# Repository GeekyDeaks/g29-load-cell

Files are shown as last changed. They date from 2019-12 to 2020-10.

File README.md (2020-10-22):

# G29 Load Cell Mod

Modification to replace the stock brake pedal sensor on a Logitech G29 pedal set with a load cell,
the purpose of which is to more closely simulate a real brake system which is dependent on
the force applied to the pedal and not the pedal position

I assume this would work on the G920 without any issues, and possibly the G27 and G25,
however I have not had the opportunity to test.

It uses a cheap load cell with two closely matched 1k resistors arranged in a
[Wheatstone bridge](https://en.wikipedia.org/wiki/Wheatstone_bridge)
and an Instrumentation Op-Amp.  The cell is mounted in a 3D printed
model that replaces the lower half of the brake piston assembly

There is a digital version by [SkiDude88](https://github.com/Skidude88/Skidude88-G29-PS4-LoadCell-Arduino/wiki) 
using an HX711, that often comes bundled with the load cells, and an Arduino

Assembly re-uses the spring and rubber block, along with a short piece of M10 rod.
The adjustment of the location of the washer and the protrusion of the top nut
allow changes to the first stage of the pedal, which is designed to simulate
the initial feel of the pedal as the pads move into contact with the disc.

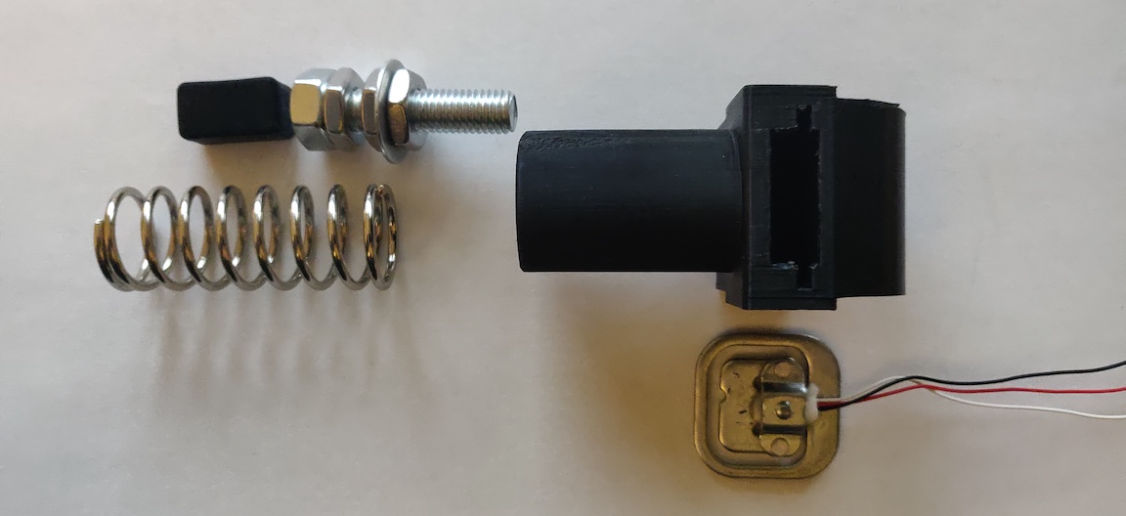
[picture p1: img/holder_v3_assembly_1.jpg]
holder parts

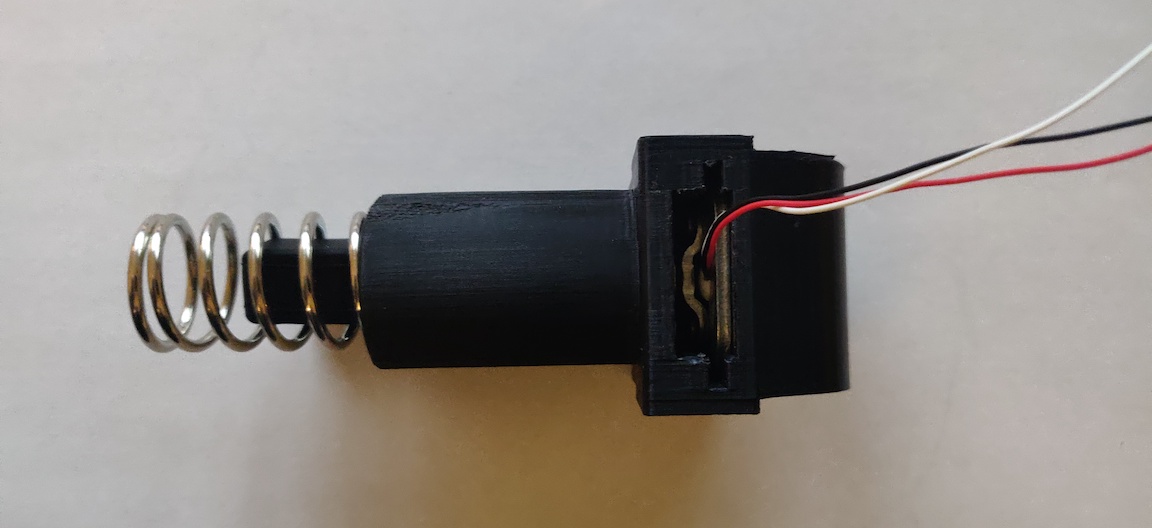
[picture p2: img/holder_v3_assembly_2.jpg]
holder assembled


Fully installed, with the amplifier circuit mounted in a small case

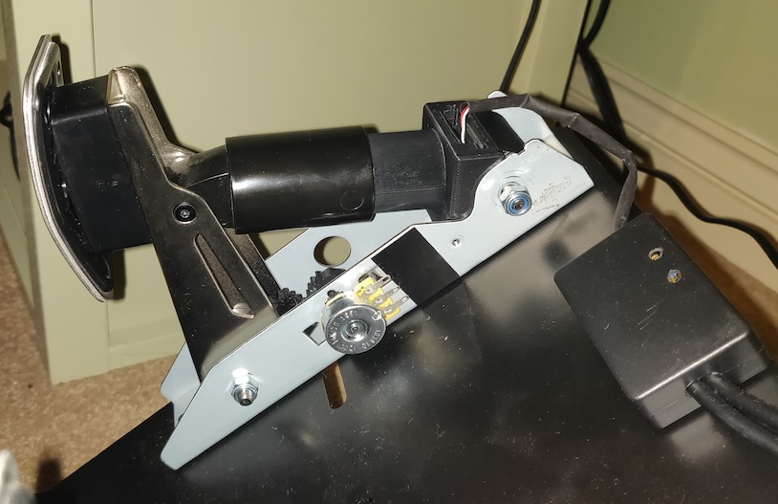
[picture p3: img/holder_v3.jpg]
load cell holder


2020-10-22 UPDATE

Working on a 3D printed plunger to remove the need to cobble one together

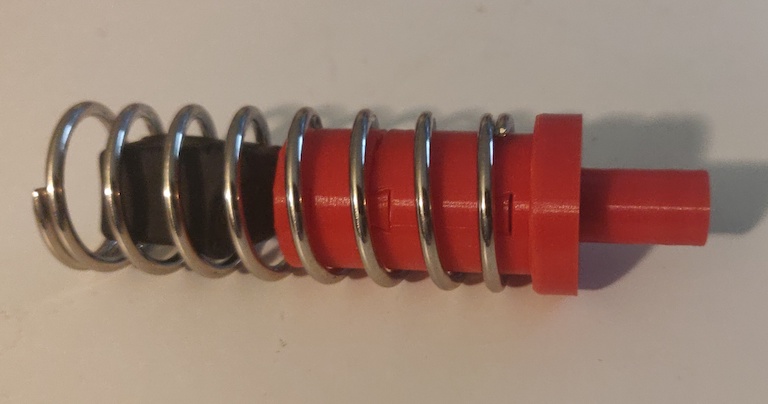
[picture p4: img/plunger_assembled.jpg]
plunger_assembled

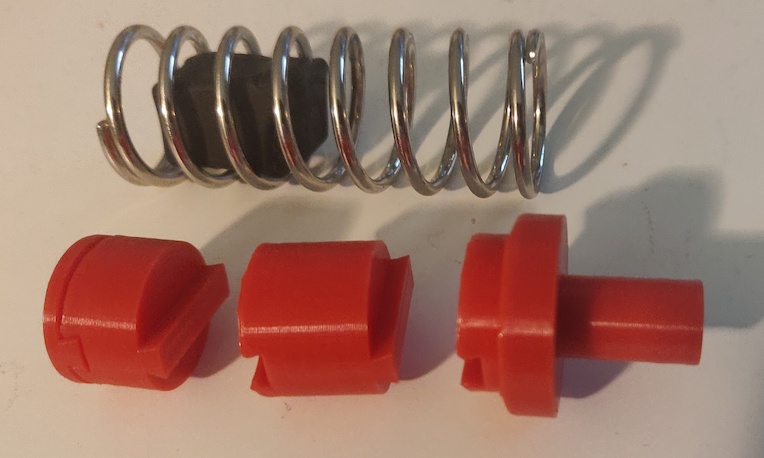
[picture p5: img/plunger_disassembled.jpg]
plunger_disassembled


# Shopping list

1. 3D printer capable of 80mm x 43mm x 43mm
2. Bathroom scale type loadcells
3. PCB copper board or stripboard (35mm x 30mm)
4. INA122P instrumentation amplifier
5. 1k trim pot
6. 10ohm trim pot 
7. 2x 1k resistor
8. 100ohm resistor (fake clutch)
9. 900ohm resistor (fake clutch)
10. M10 thread ~30mm
11. 3x Half height M10 nuts
12. 1x M10 nut
13. M10 to 24mm washer

# Software used

1. EAGLE https://www.autodesk.co.uk/products/eagle/free-download
2. Fusion 360 https://www.autodesk.com/campaigns/fusion-360-for-hobbyists

# Load Cells

The load cells are cheap bathroom scale variety.  I got mine from Amazon:

https://www.amazon.co.uk/gp/product/B07TWLP3X8

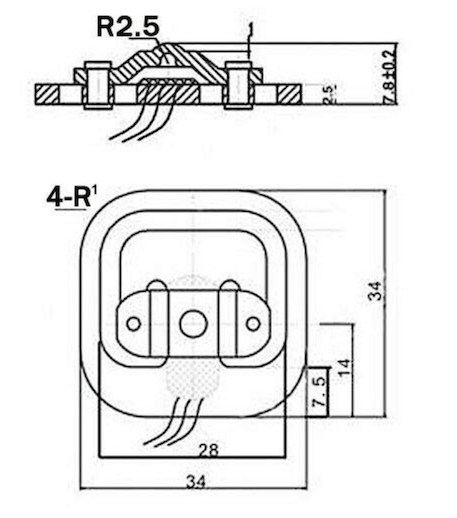
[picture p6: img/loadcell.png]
load cell dimensions


Each cell is comprised of two resistors one which increases under load (white) and the 
other which decreases (black).  Zero load is approx 1k, with about 2-3 Ohm change under heavy load

# Amplifier Circuit

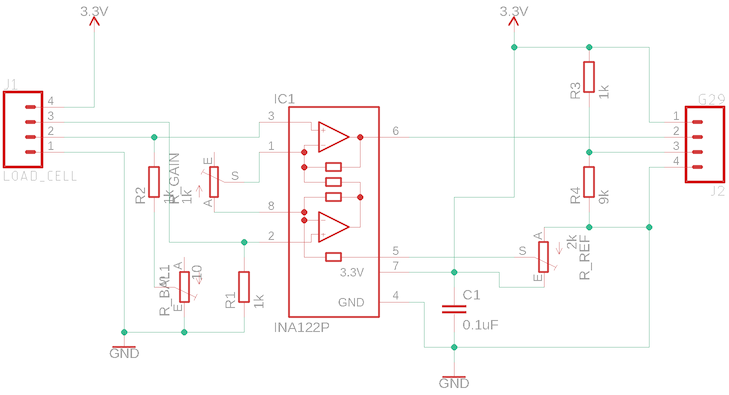
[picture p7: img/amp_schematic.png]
amp schematic


The loadcell is connected to the circuit as follows:

1. Red -> 3.3v
2. Black -> V+
3. White -> V-

Since we need to output a higher voltage with no load on the cells 
we have to unbalance the bridge so that load brings it back into balance.

The 1k resistors for `R1` and `R2` should be measured and the larger of the two should
be used for `R1` to allow `R_BAL1` to adjust the link with `R2` and force the bridge out of 
balance with no load

`R_REF` should be replaced with a link from the middle pin to the right pin.  This
will tie the `REF` pin on the INA122P to ground.
It was originally used when the design had two load cells
and the INA122P was inverting the gain.

Astute observers may have noticed the connections for the loadcell appear to be
reversed in reference to V+ and V-.  This is because the labelling on the PCB of 
V+ and V- was in reference to the dual load cell configuration and hence the 
labels on the PCB are not correct for a single cell.

## Clutch

The circuit also allows for simulating a clutch, allowing it to be removed if desired.
The G29 has been known to glitch if the clutch is disconnected and the leads left hanging.

If you do not need this feature, you can leave `R3` and `R4` unpopulated on the board

# PCB

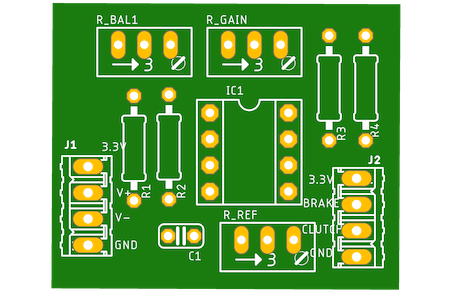
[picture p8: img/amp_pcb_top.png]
amp pcb top

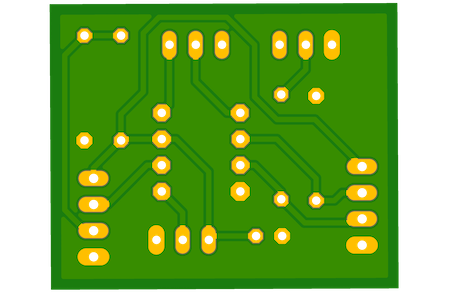
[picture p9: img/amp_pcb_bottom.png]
amp pcb bottom


The PCB design is a little tricky to manually etch, so we came up with a slightly
larger design to help.  Note that this is a mirror image to print and apply to
the copper via toner transfer.  You can find a pdf with the correct size [here](pcb/load_cell_amp_diy.pdf)

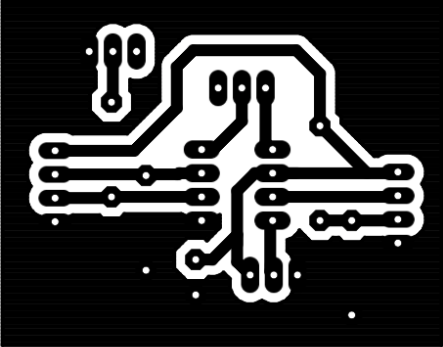
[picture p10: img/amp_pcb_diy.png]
diy pcb


# STL model

Previous prints have been done with the model on it's side.  This was to ensure the grain
in the upper cylinder was along the length of the cylinder

- 30% infill
- 5% support

[stl/single_holder.stl](stl/single_holder.stl)

The plunger is comprised of several sections.  It is recommened to print the bottom section with 100% infill

- [stl/plunger_bottom.stl](stl/plunger_bottom.stl)
- [stl/plunger_spacer_5mm.stl](stl/plunger_spacer_5mm.stl)
- [stl/plunger_spacer_10mm.stl](stl/plunger_spacer_10mm.stl)
- [stl/plunger_spacer_15mm.stl](stl/plunger_spacer_15mm.stl)
- [stl/plunger_top.stl](stl/plunger_top.stl)

# G29 brake levels

From reading around it seems that there is not an agreed set of values for what represents
min and max braking.  Below is a table I took from attaching an AVO directly to the middle pin 
of the brake potentiometer on my set and monitoring the output on the PS4:

| Level | Voltage |
|---:|---|
| 0% | 3.0 |
| 25% | 2.5 |
| 50% | 2.2 |
| 75% | 2.0 |
| 100%  | 1.9 |

# Pedal Pin Outs

    -----------------------
    \  1   2   3   4   5  /
     \   6   7   8   9   /
       -----------------

| Pin | Role | Colour
| --- | --- | ---
| 1 | Gnd | Black
| 2 | Throttle  | Orange
| 3 | Brake | White
| 4 | Clutch | Green
| 5 | NC |
| 6 | +3.3v | Red
| 7 | NC |
| 8 | NC |
| 9 | +3.3v | Red

The above values were taken by removing the wiring loom from the pedal set
and measuring at the spade connectors.
Note that these pin outs are different to those reported by others for the G27
with +3.3v and Gnd switched

# Inspiration

This is a popular mod and others have come before with interesting designs that you may also
want to take a look at:

- https://www.reddit.com/r/simracing/comments/92exmk/diy_load_cell_brake_for_g29_with_native_ps4/
- https://www.racedepartment.com/threads/low-budget-load-cell-mod-for-logitech-g25-g27-g29.167760/
- https://imgur.com/gallery/gOjAf#SXX5zrY
- https://www.racedepartment.com/threads/logitech-g25-g27-g29-g920-load-cell-diy-project.174623/

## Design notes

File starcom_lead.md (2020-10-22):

# Starcom 2m 9pin lead

https://uk.rs-online.com/web/p/serial-cable-assemblies/1864044/

    -----------------------
    \  1   2   3   4   5  /
     \   6   7   8   9   /
       -----------------

| Pin | Role | Colour
| --- | --- | ---
| 1 | Gnd | Brown
| 2 | Throttle  | Red
| 3 | Brake | Orange
| 4 | Clutch | Yellow
| 5 | NC |
| 6 | +3.3v | Blue
| 7 | NC |
| 8 | NC |
| 9 | +3.3v | Black

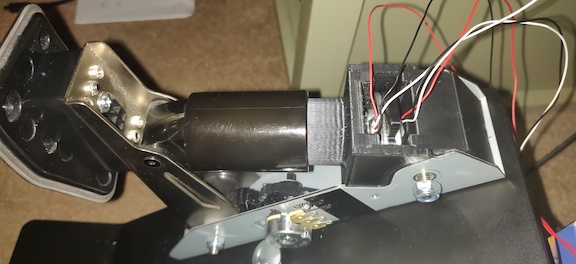
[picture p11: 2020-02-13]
img/holder_v1.jpg

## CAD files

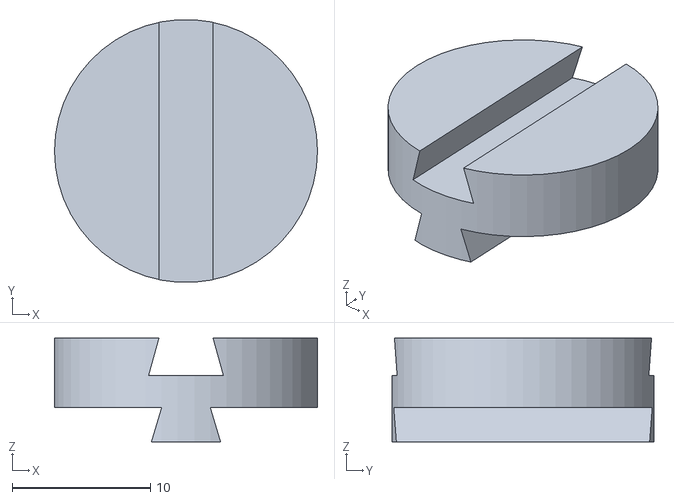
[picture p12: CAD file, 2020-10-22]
stl/plunger_spacer_5mm.stl
19.0 x 19.0 x 7.50

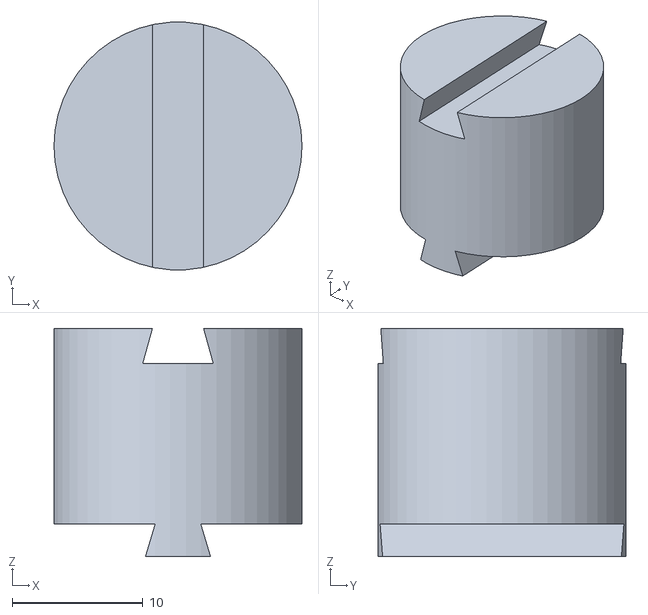
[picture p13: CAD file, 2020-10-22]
stl/plunger_spacer_15mm.stl
19.0 x 19.0 x 17.5

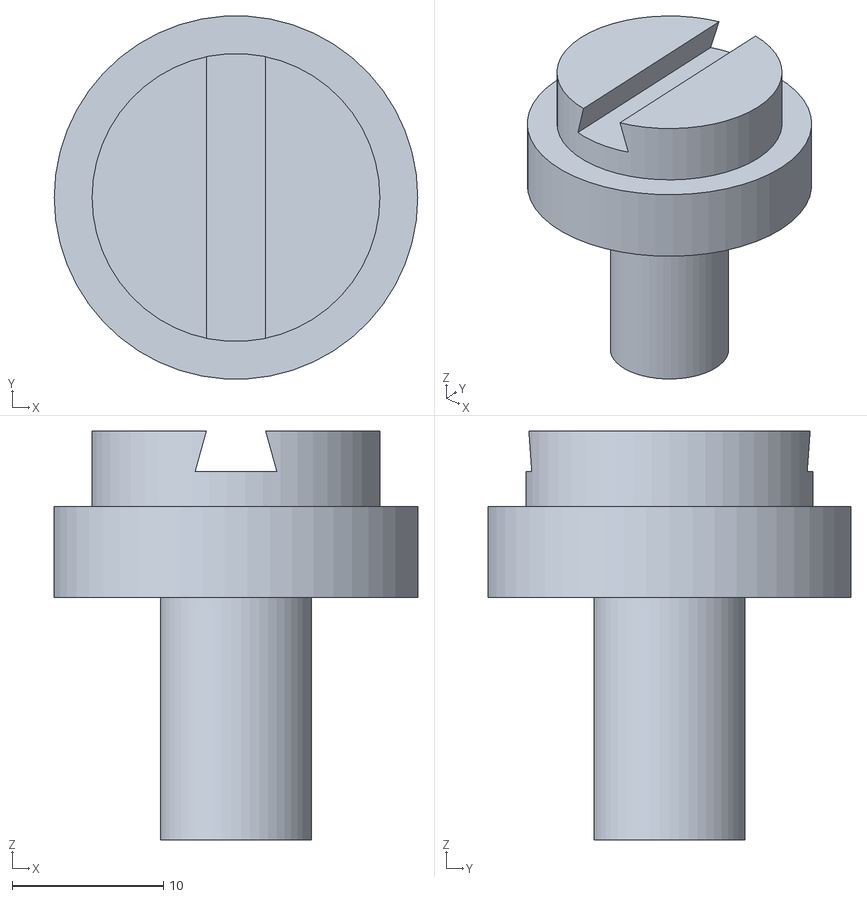
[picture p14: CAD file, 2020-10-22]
stl/plunger_bottom.stl
24.0 x 24.0 x 27.0

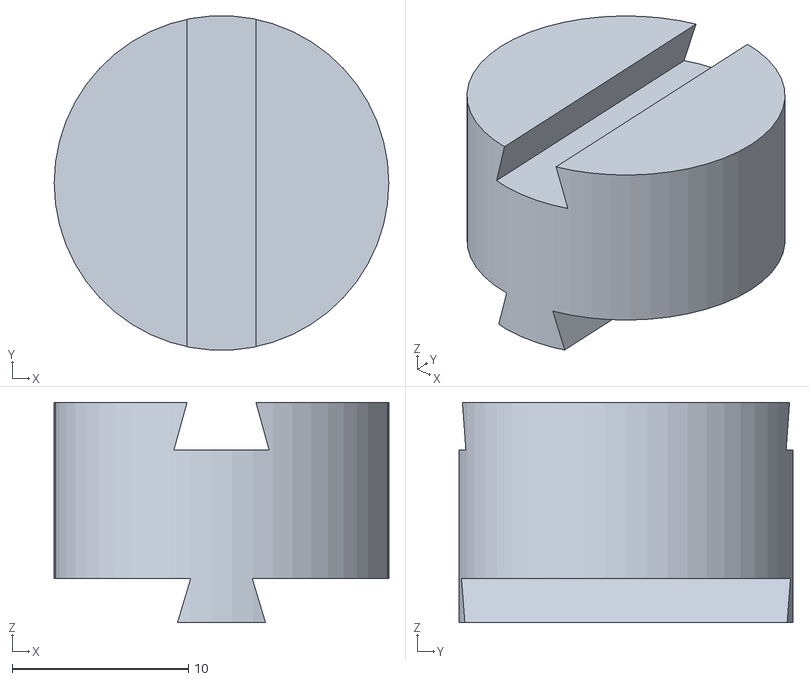
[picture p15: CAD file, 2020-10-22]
stl/plunger_spacer_10mm.stl
19.0 x 19.0 x 12.5

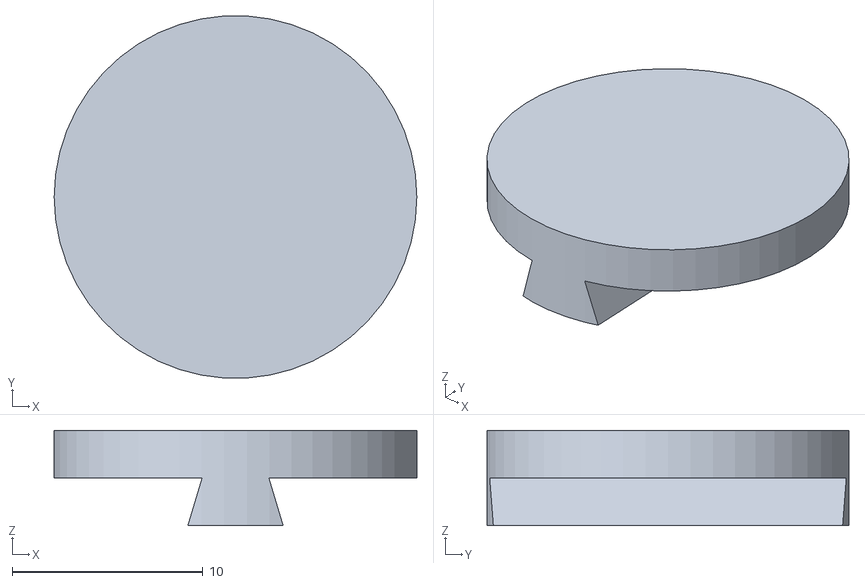
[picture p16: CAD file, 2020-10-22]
stl/plunger_top.stl
19.0 x 19.0 x 5.00

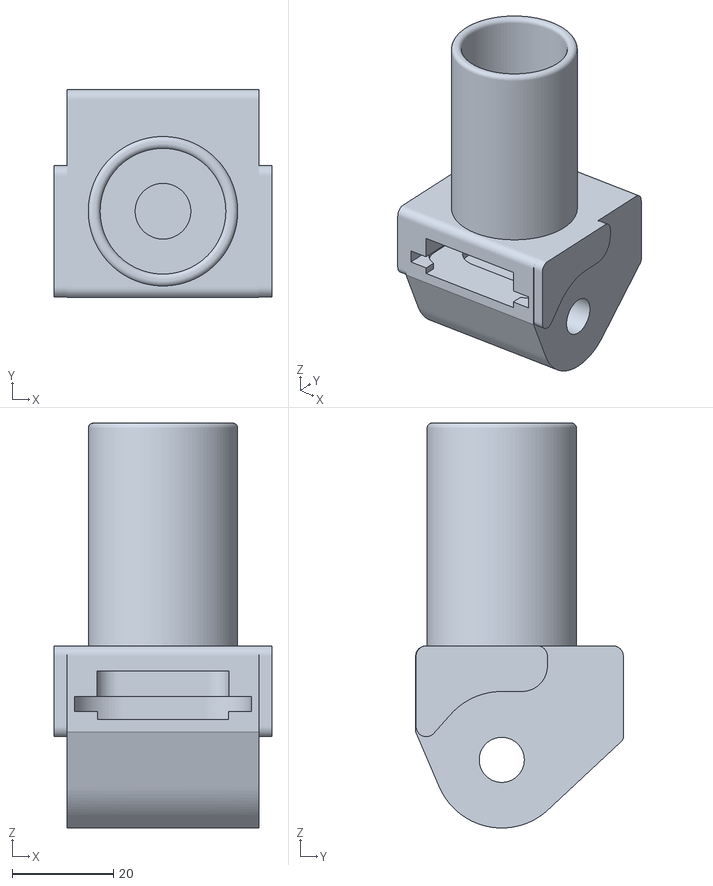
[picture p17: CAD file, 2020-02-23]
stl/single_holder.stl
43.0 x 41.0 x 80.0

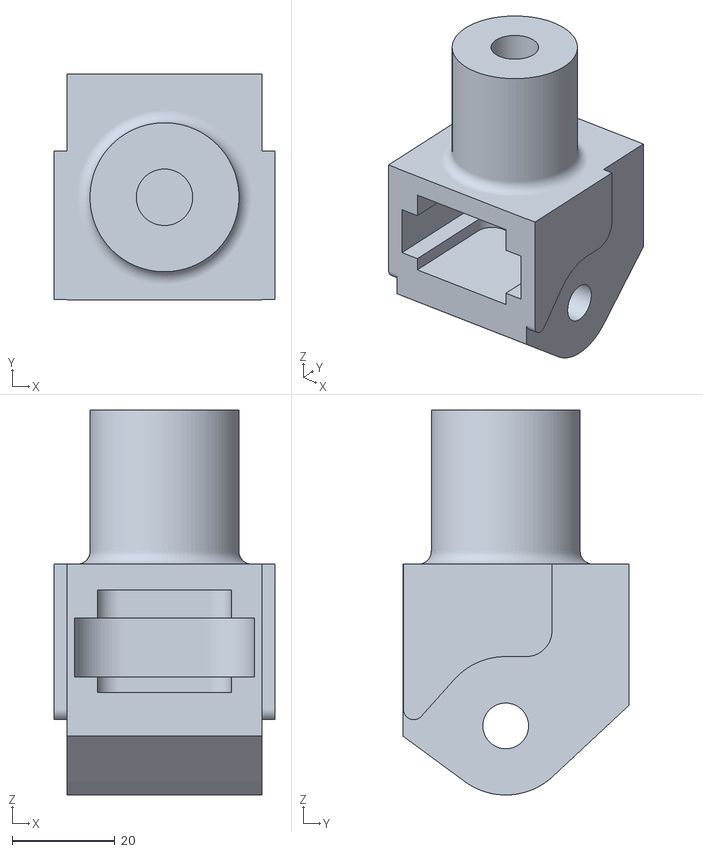
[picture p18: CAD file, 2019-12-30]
stl/dual_holder.stl
43.0 x 44.0 x 75.0

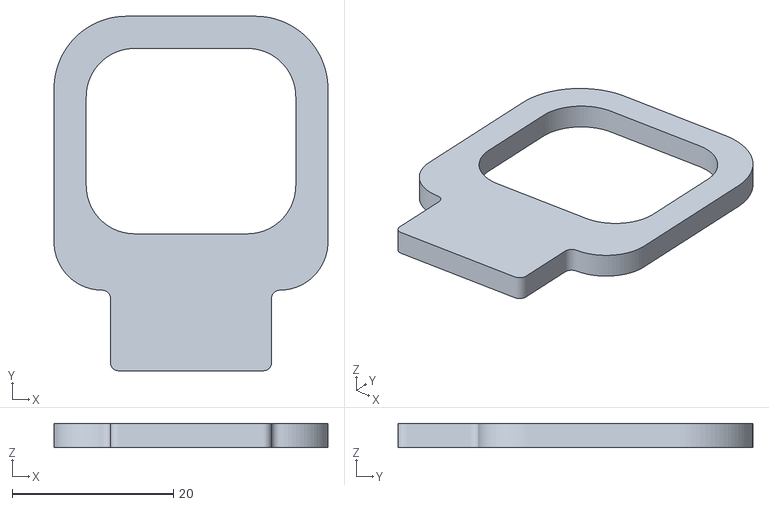
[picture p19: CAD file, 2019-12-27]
stl/dual_spacer.stl
34.0 x 44.0 x 3.00

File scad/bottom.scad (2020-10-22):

use <plunger.scad>;
bottom();

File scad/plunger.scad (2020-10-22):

$fn=50;

// bottom of plunger where it engages with the loadcell
LOWER_HOLE_DIAMETER=10;
LOWER_LENGTH=16;

SPRING_REST_HEIGHT=6;

SPRING_OUTER_DIAMETER=24;
SPRING_INNER_DIAMETER=19;

// UPPER_LENGTH=28;

UPPER_LENGTH=5;

module dovetail(offset=0, length=SPRING_INNER_DIAMETER) {

    width=5;
    height=2.5;
    rebate=0.75;
    translate([0, 0, - height - offset])
    intersection() {
        cylinder(d=length, h=width + offset);
        rotate([90, 0, 0])
        linear_extrude(height = length, center = true)
        translate([-width/2, 0, 0])
        polygon([
            [0 - offset, 0],
            [rebate - offset, height + offset],
            [width - rebate + offset, height + offset],
            [width + offset, 0]
        ]);
    }

}

module spacer(height=10) {
    difference() {
        cylinder(d=SPRING_INNER_DIAMETER, h=height);
        translate([0, 0, height + 0.01])
        dovetail(offset=0.2, length = SPRING_OUTER_DIAMETER);
    }

    dovetail();

}

module bottom() {
    cylinder(d=LOWER_HOLE_DIAMETER, h=LOWER_LENGTH);

    translate([0, 0, LOWER_LENGTH])
    cylinder(d=SPRING_OUTER_DIAMETER, h=SPRING_REST_HEIGHT);

    translate([0, 0, LOWER_LENGTH + SPRING_REST_HEIGHT])
    difference() {
        cylinder(d=SPRING_INNER_DIAMETER, h=UPPER_LENGTH);
        translate([0, 0, UPPER_LENGTH + 0.01])
        dovetail(offset=0.2, length = SPRING_OUTER_DIAMETER);
    }
}

module top() {
    union() {
        cylinder(d=SPRING_INNER_DIAMETER, h=2.5);
        dovetail();
    }
}

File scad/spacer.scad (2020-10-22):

use <plunger.scad>;
spacer(15);

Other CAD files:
scad/top.scad

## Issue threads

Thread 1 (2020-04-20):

Plunger hole size

Locoblade, 2020-04-20:
Hi, many thanks for sharing all this, I'm currently in the process of sourcing the parts I need to mod my G25 pedals and this has been invaluable.

Just one query I've got, looking at the STL file I noticed the 3D printed part has a 11mm hole which seems quite big for a 10mm bolt to pass through and I was just wondering whether you'd had any issues with the bolt binding on the plastic or not sitting square in the hole and whether there'd be any benefit to making the hole a slightly snugger fit, say ~10.2mm?

cheers

GeekyDeaks, 2020-04-20:
Hi @Locoblade.  I have to confess that I don't remember exactly why the tolerance was so big.  I think my friend with the printer suggested that the model could bleed about 0.2mm, but that doesn't quite explain it.  I can say however that the slack is not noticeable in practice.  I think partly this is because the amount of movement the plunger undergoes is very slight.

I realise now that I forgot to include the original Fusion files in the repo.  I'll add them later this week to allow you to experiment if you like

Locoblade, 2020-04-21:
Thanks for getting back to me, yeh you're right about the small amount of movement probably helping but having the Fusion files to play with would be great, many thanks!

Locoblade, 2020-04-21:
Just thought I'd update as a friend did a test 3d print for the base of the piston for me today and I had a couple of hours to play around making and trying a variation for the plunger with bits I had lying around which may be an additional source of ideas for others.

I used a 10mm bolt with the head chopped off as the basis to give a smooth section for passing through the lower housing, and I decided to try and dampen the plunger from below using some rubber (an old MTB handlebar grip I cut up) rather than use a spring. Initially I had the top of the plunger full length inside but I found with the rubber compression alone there was too little travel and it was too stiff so I found a small spring, chopped the top of the plunger down by about 10mm then put a sliding collar and a couple of washers on top which pushes against another larger ring of rubber in the top housing (a cut piece of car radiator hose). This way when the pedal is depressed the collar and spring start to compress first to give an initial soft-ish pedal (the rubber in the top is primarily there to give the top of the plunger some space to move into, it doesn't add much to the damping), then after about 10mm of pedal travel the top of the plunger touches against the top of the housing at which point the rubber at the bottom starts getting compressed to ultimately push out of the bottom of the housing and against the load cell.

I haven't actually received the load cell yet due to postage delays, so may need to adjust the damping and the throw a little so once that's nailed down I'll get rid of the upper washers on the plunger and make a single collar exactly the right length, but I put everything back together as-is still working with the original potentiometer and the pedal feel in-game is already a load better.

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

GeekyDeaks, 2020-04-21:
oh, that looks pretty cool!  I'll knock up something similar over the weekend and give it a go too

GeekyDeaks, 2020-04-21:
Also, I forgot to mention, but I have some spare PCBs if you want one

Locoblade, 2020-04-22:
Cheers, just sent you a PM on RaceDepartment rather than fill Github up with our chat :)

GeekyDeaks, 2020-04-22:
Hey @Locoblade - I started to get the parts to replicate your idea, but I noticed something I wanted to check with you.  Is the lower rubber tube intended to be compressed?  If so, I am not sure how mechanically this will work since the bottom of the plunger needs to be in contact with the top of the load cell.  I suspect trying it without the cell is giving a nice feel because the plunger is moving a fair bit.

This is really a downside to the design and in hindsight I would have ensured the loadcell was offset to the axis of the plunger to allow it to travel.  With the design as it stands, you need the compression at the top of the plunger, but I think you could simply increase the length of the top rubber to allow it to compress once the spring has compressed?

Locoblade, 2020-04-22:
Without having the load cell to hand I wasn't sure if it would provide sufficient resistance on it own or how far it travelled plus I also thought having something there to push the plunger back up could give the option to set it up not quite touching the load cell at rest creating a short dead zone with zero output before it starts to activate much like you get in a real car taking up the gap between pad and disc. I see what you mean though and you may well be right as that amount of rubber in addition to the load cell may well be too stiff and once my plunger has engaged with the load cell the only thing providing any additional pedal movement is the remaining travel in the spring if the plunger hasn't already hit the top of the upper body, so I may need to add more rubber damping at the top like you suggest.

GeekyDeaks, 2020-04-22:
The loadcell deforms a little, but it really is a tiny amount and I suspect you will be unlikely to notice it via your foot.

I'd just recommend having a bit of a play once you get the loadcell as it will make more sense once you get to experience the amount of flex it has, but I just wanted to forewarn you that your current idea might not work exactly as intended in it's current configuration.

It kind of depends on how 'hard' you want the feel in the end though.  Version one of the model https://github.com/GeekyDeaks/g29-load-cell/blob/master/stl/dual_holder.stl had very little space for compression and gave a very 'racey' feel, but it just felt too hard for me and I wanted a more spongy 'road car' feel  - or as my friend put it - they need bleeding :)

Locoblade, 2020-05-01:
Just to update what I ended up with for the pedal setup (with an extra locking nut on the bottom I put on after the photo was taken). Note I've got rid of the rubber under the plunger and flipped the bolt around so the spring and sliding aluminium part is now on the smooth section, I did this as I found the spring was grating against the threads when the other way around which made the pedal really notchy to use. This way although the thread is passing through the damper body hole, like you I find the movement is small enough that it doesn't have a significant effect on smoothness.
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

This car radiator hose goes in the top section of the damper body to allow the sprung rod to move. It adds a small amount of give but you could use something more solid like wood or plastic with a hole in it if required
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

The sliding aluminium plunger needs to be long enough to sit partially inside the lower body of the damper at rest to prevent it catching on the lip when depressed and locking up the entire mechanism
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

Not a great photo but total length of the rod is ~63mm and the spring is just under 20mm. Not sure where the spring came from or it's strength unfortunately as I found it in my "box of odds and sods" in the garage, probably compresses fully with about 10-20kg of force at a guess. The aluminum plunger (not shown) is about 15mm long.
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

Locoblade, 2020-05-11:
Quick update with completed photos of the Leobodnar install, there's not too many places to mount the board inside the pedals as there's lots of strengthening ribs everywhere, but found a home for it and hot glued it in place alon with the little home made resistor circuit. I also made small notches in the plastic ribs for the accelerator and clutch wires to pass through and be glued so as not to be trapped when putting the lid back on and I had to make one small cut in a rib to allow for the USB cable end to pass through. I also took the carpet grip out from the bottom of the pedals as I mount them on a wheel stand and taking that out gives you a couple of openings to pass the USB cable out from inside without having to drill any holes in the exterior. of the casing, and I used a short 30cm USB Type B male to female extension cable (a few £ on ebay) so I didnt have to trap a long USB cable inside the housing for connecting directly to the PC.

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

bruxaodev, 2023-11-15:
Two 50kg cells in series would increase the maximum weight by around 100kg or just the precision?

GeekyDeaks, 2023-11-16:
> Two 50kg cells in series would increase the maximum weight by around 100kg or just the precision?

Just the precision as it will double the voltage range from the wheatstone bridge.  You'll need to put them in parallel to also increase the range of the weight as that will distribute the load across the two.

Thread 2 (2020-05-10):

Dual holder 3D model is different?

JMik3, 2020-05-10:
Hi, thanks a lot for sharing you project.

I just want to ask you why the Dual Holder is completely different. How it is supposed to be used.

I am interested in using the Dual holder to have a full bridge and connect it to the Leobodnar BU0836-LC.

The single holder 3D model is easy to understand but the Dual Holder I am not sure why it is like that.

Could you please explain it and how to mount it?

PD: sorry if my english is not good enough :).

GeekyDeaks, 2020-05-10:
Hi @JMik3

It's a bit of a long story, but the short answer is that it was the first attempt at the model and it had some issues.

To elaborate a bit more, we found the following problems:

1. the model doesn't fit inside the case - this was not a problem for me because I had mounted them outside the case, but my friend was still using his and we had to hack quite a bit of the model away to get it to fit.
2. There is very little room at the top of the model for allowing compression.  I didn't really think this through fully at first, but because the piston has to always be in contact with the loadcell, it means all the compression has to occur at the top of the piston.  Since we left very little room, the pedal felt really hard
3. The two loadcells have to be able to move very slightly down, this meant you need a little spacer between the two to stop the top one simply resting on the bottom one and preventing it from working.  In CAD it looked OK, but when it was printed the two cells would just rattle around
4. finally, and probably most importantly, I made the mistake of thinking the two cells would give a 50kg range, but this doesn't work when they are in series, so other than getting slightly better resolution the added complexity to the design didn't seem worth it

I'll dig up some pictures of how the piston was assembled with the dual cell, but there is actually a photo of it in place that might help for now in the [code](img/holder_v1.jpg)

GeekyDeaks, 2020-05-10:
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

Hopefully in the above you can see the two cells and the little spacer in between.  The spacer model can be found in the code [dual_spacer.stl](stl/dual_spacer.stl)

GeekyDeaks, 2020-05-10:
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

Another photo showing some rubber washers on the bolt I was using as the piston.

GeekyDeaks, 2020-05-10:
I just looked at the BU0836-LC - I think you can simply use two 1k resistors to make the other side of the bridge and then stay with the single cell model.  I can help with the circuit if you want as it would be trivial and you can probably mount the resistors directly to the screw terminals of the board

GeekyDeaks, 2020-05-11:
Hey @JMik3, I just realised that @locoblade already posted a diagram with the same board and the two extra resistors.  You can find it at the end of #1

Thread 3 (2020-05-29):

Wiring connections

drclong, 2020-05-29:
Hi GeekyDeaks, Thanks heaps for your project, I am in the process of construction but am unsure of the wiring connections. I am a complete novice with electronics so please bear with me. I am using single load cell setup. Could you please clarify the following?

1. Is the cap still required with 1 cell?
2. I am confused as to exactly which wire goes where as I thought the load cell would have a ground connection.

Looking at the instructions, it seems that the cell connections are as follows:
Red -> 3.3v
Black -> V+ (V- on PCB?)
White -> V- (V+ on PCB?)
No GND?
Is this correct?
Thanks so much for your help.

rjm83, 2020-05-29:
I used the Leo Bodnar board and not a custom PCB, but I wired it as 5v to white, red to V-, and gnd to black.  I split from ground/black with a 1k resistor and from white/5v with another 1k resistor then brought together the other side of the two resistors to single wire into v+.  This completes the wheatstone bridge and the difference in voltage from v- and v+ is the load registered.  Reference the wheatstone bridge image shown in the original readme or in other issues/comments.

drclong, 2020-05-30:
> I used the Leo Bodnar board and not a custom PCB, but I wired it as 5v to white, red to V-, and gnd to black. I split from ground/black with a 1k resistor and from white/5v with another 1k resistor then brought together the other side of the two resistors to single wire into v+. This completes the wheatstone bridge and the difference in voltage from v- and v+ is the load registered. Reference the wheatstone bridge image shown in the original readme or in other issues/comments.

Thanks for the reply but I am trying to copy this circuit exactly and there are no images of the finished board and wires that I can find.
Cheers.

GeekyDeaks, 2020-05-30:
Hi @drclong - you are correct.  The PCB design shared on the project page does not connect GND directly to the Loadcell.  I'll go into specifics in a bit, but here are the main points you raised:

- `R_REF` is directly connected to `GND` (this was used for the dual load cell as we ran the amp in a negative gain configuration)
- Install the cap `C1` if you can - it's just for decoupling the amp from the power to help smooth the supply to it, but I found the circuit wasn't particularly noisy so you may get away with it

That's a good call on the constructed board.  I'll try and make another one up this weekend and take a photo.  If you want a PCB, I have some spare and I'm happy to post one to you.

To go into a little more detail around why there is no GND connection to the load cell.  It helps to remember that the load cell is simply just two resistors in series and not an active device.  In the model used in this project, the red wire goes to the mid point between the two resistors and the black and white are connected to the ends of the resistors.  Since there are only two resistors in a single load cell, this means you need two more to construct the entire wheatstone bridge.  The post by @rjm83 highlights the fact that there is more than one way to do this.  I choose to have the load cell take the place ofthe upper two resistors (with respect to V+ and GND), but @rjm83 choose to have the load cell take the place of two resistors to a side (this might have been dictated by the circuit on the bodnar board).  If you take a closer look at the circuit diagram, you will see that the load cell is connected to GND via `R2 + R+BAL1` and `R1`.  These two resistors and trimpot are the lower part of the wheatstone bridge.

tazea, 2022-12-03:
Hi, sorry to revive this old but gold thread. Im wiring a strain gauge as [rjm83](https://github.com/rjm83) did, however ive got a very small change in the output of the INA, resulting in a very poor resolution. I believe using two strain gauges as half bridge would increase the sensitivity of the bride, but, is there any way to increase the output with only one cell?

Ive tested a 4 wire loadcell and the output is perfect, 0 to 5v but im trying to achieve a considerable same result with only one strain gauge, is that possible?

Thank you..

GeekyDeaks, 2022-12-03:
hi @tazea ! Whilst using one load cell will reduce the resolution, at worst it should be half of that with two and in practice I found this was something I could not perceive through the pedal.  You should still be able to double the amplification used for the dual load cell to get the full range with a single, so it sounds like something isn't quite right if the output from the amp cannot get close to 5v.  Are you able to provide some pictures of your setup?  I'd probably start with checking what the mV input to the amp is like when idle and under load with both the dual and single load cells to see if there is a big disparity there.  It might be that the single load cell is -ve when idle due to tolerances on the other side of the bridge, which would reduce the range.

neilser, 2022-12-04:
> Hi, sorry to revive this old but gold thread. Im wiring a strain gauge as [rjm83](https://github.com/rjm83) did, however ive got a very small change in the output of the INA, resulting in a very poor resolution. I believe using two strain gauges as half bridge would increase the sensitivity of the bride, but, is there any way to increase the output with only one cell?
>
> Ive tested a 4 wire loadcell and the output is perfect, 0 to 5v but im trying to achieve a considerable same result with only one strain gauge, is that possible?

Just in case there's a misunderstanding here: each of the bathroom-scales type of load cell is in fact a **pair** of strain gauges (in a half-bridge arrangement). You mention "only one strain gauge" and "only one cell" in a way that makes me wonder if you are considering them as being equivalent. Perhaps though you are using a different type of load cell with only a single strain gauge?

tazea, 2022-12-04:
hi! @GeekyDeaks thanks for your reply, im measuring the output of the loadcell and its 24.4 mV when idle and it goes up to around 27+ mV when full pressure. is it possible to offset the output to 0 v when idle so i can get full output with the amplifier? im currently testing one loadcell while waiting for the other to arrive. Its connected with 2 1k resistors 5% tolerance.

@neilser yes sorry for the misunderstanding, i meant using 2 straing gauges as a full bridge..

tazea, 2022-12-05:
@GeekyDeaks Thank you for your fast reply! so far its working better now, i measured the output of the strain gauge without no load and it was around 24.5 mV, so i missed the "unbalance" the strain gauge thing to balance its output to 0 when no load. Ill keep working on it tomorrow to polish some things. so far so good.

@neilser sorry for the missunderstaing, i meant 2 strain gauges as a full bridge, i dont know why i said half.

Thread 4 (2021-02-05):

Can't reproduce measurings on Load Cell

nldroid, 2021-02-05:
Hi,

I bought a load cell and fail te get it working so i tried measuring the resistance between red/white and black/white.

This is what i read on your page"

_"Each cell is comprised of two resistors one which increases under load (white) and the other which decreases (black). Zero load is approx 1k, with about 2-3 Ohm change under heavy load"_

My load cell behaves differently. Both sides increase when pushing on it.. Is my load cell faulty? Of do i need a different one?

GeekyDeaks, 2021-02-05:
be super careful how you are applying load.  I have found that if do not apply load to the top of the small bridge attached to the smaller arms and ensure that the outer is correctly supported allowing the middle section to move down, then the result is often as you have found and both resistances will change in the same direction

nldroid, 2021-02-05:
Thanks for your quick reaction. I'll test it within your 3D part.

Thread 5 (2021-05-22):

Does this mod works well on PS4

kopi4life, 2021-05-22:
Hi GeekyDeaks,

Just wondering, does this load cell brake mod will work well on console? Since you did reverse the voltage to actually match the voltage on the potentiometer, i guess it would work. I just need any clarification on that matter or maybe anyone who’ve done it had tried it on the console. Thank you

GeekyDeaks, 2021-05-24:
Hi @kopi4life.  Yes, it does work on console.  One of the goals of the project was that I would still be able to use the pedal set with my PS4, although I only used it for a few months before buying a PC.  If you take a close look at the amplifier circuit, you will see that we deliberately unbalance the wheatstone bridge so that it has a voltage offset with no load, but applying load brings the bridge into balance, therefore reducing the voltage.  It means some careful tweaking of the pots to make all this work though.

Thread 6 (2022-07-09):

No input

GioVatti, 2022-07-09:
Hello, I am a noob in electronics and I tried to follow this project withnot much success. At first it acted like there wasn't anything attached (oscillating at around 15% brake), then I modified the circuit adding cables that connect all ground to the pedal metal chassis and it now does the same thing but at around 3%... there are many things that can have gone wrong:
1) Defective components from China
2) I ruined some components while soldering/by making a circuit that sends power where it shouldent
3) By having got the whole thing wrong.
4) got the wrong resistors
I have a backup loadcell and a backup INA122, but since I fear I might ruin those too, here I send a quick drawing (sorry for the poor quality) of my circuit as it stands. Also worth noting that if I test the voltage between the red cable from any of the pedals and ground, it reads 6.3v, so I either do not know how to test it or maybe it could be that the G920 has a different voltage than the g29, which seems weird. Thanks for your time!
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

GeekyDeaks, 2022-07-10:
Hi!

At first glance, the circuit you have drawn looks fine, so I guess some simple troubleshooting tips would be the next step.

First, I'd check that the voltages into the amp look ok, especially since you mention seeing over 6v.  Could you measure the voltage between the following pins please?

- 4 and 7 - should be around 3.3v
- 4 and 3 - should be around 1.65v
- 4 and 2 - should be around 1.65v
- 3 and 2 - should be < 50mV (you'll need to pay close attention to the scale on your multimeter for this one). Don't worry about exact numbers as this is the value you have to tweak to calibrate, it just has to be pretty small

The first 3 will give an indication if something is not wired up correctly.  The last one gives an idea about how far out the initial calibration is as this voltage difference is the thing that actually gets amplified.

The calibration is a bit of a dance between tweaking the 10ohm pot (which tweaks the balance of the bridge) and the 1kohm pot (which tweaks the amplification of the voltage between pins 3 and 2).  The reason for this is because the G29 works in reverse, taking a higher voltage as less brake pressure, so we have to have unbalance the bridge to allow the circuit to provide the higher voltage with no load.

GioVatti, 2022-07-11:
Thanks for spending some time to reply.
First of all, I realised I was using my multimeter in AC mode, ence the
6.3v. on the red cable I could measure 3.22-3.27V, which is the same I
measured between pin 4 and 7. Both pin 4 to pin 3 and pin 4 to pin 2
measured around 1.63v, so it is looking good enough for the
connections.between 2 and 3 however there was a difference of just 10mV(if
I got the scaling right). Does this mean I just have to calibrate to
unsettle the bridge?
Thanks again,
Gio

Il dom 10 lug 2022, 10:52 Scott Deakin ***@***.***> ha
scritto:

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

GioVatti, 2022-07-12:
Little update: I tried tweaking the 10 ohm trimpot and got the voltage
between 2 and 3 within the right value (4.4 mV as now). It still flickers
at around 3% and it doesn't seem to be affected at all by the 1k ohm
trimpot tweaking and by any force I try to apply on the loadcell...
I also tried to use the spare components I had to replicate the same
circuit on a breadboard but still nothing, so I don't think I have ruined
any components by soldering or sending power through a wrong circuit. May
my problems e related to the fact I'm using a ina122PA instead of the
ina122P?

Il lun 11 lug 2022, 13:50 Giovanni Vatti ***@***.***> ha
scritto:

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

GeekyDeaks, 2022-07-12:
Ok, that all looks very promising, except for no change when applying force of course!

So, going back to some values to look for.  The G29 wheelbase does a bit of auto-calibration to accept a bit of voltage variance.  From testing my buddy and I did, we found that the biggest range it would accept a voltage between 1.47v (100% brake) and 3.15v (0% brake), so I'd aim for something just within that e.g 1.5v to 3.1v as a starting point and then maybe reduce the top or increase the bottom as required.

To do this though, I'd start at the voltage coming in via the 10ohm pot (i.e. between pins 2 and 3).  You are looking to try and get the voltage there to approximately halve (-50%) when the pedal is fully pressed.  e.g. if you are seeing 4.4mv with no load, you want to see if you can get it to 2.2mv under load.  If the mv goes up when you press the pedal, then that means the bridge is balanced the wrong way.  You can try a couple of things to help swing it the other way.  First just switch the black and white leads on the loadcell.  If that doesn't help, try switching R1 and R2.

Please note that the tolerances that affect the bridge balance are *very* small and the load cells only change about 2-3ohms under full load, which is less than 0.5%, so if R1 and R2 have a tolerance of 5% (gold band), then they could be as much as 50 ohm in difference and this will totally mess up your day!  You might want to check R1 and R2 and match them as close as possible if you can.

GioVatti, 2022-07-25:
Got back from a short vacation and discovered that the other circuit I had
found cannot work as it only works with full bridge load cells... At this
point I have no idea what I can do to make this work.

Il mer 13 lug 2022, 19:18 Giovanni Vatti ***@***.***> ha
scritto:

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

GioVatti, 2022-10-11:
I had to switch the cables as it was going up, but now they are going down
(I couldn't get it to half, but it's probably because I couldn't press it
hard enough as I don't have it properly mounted yet). Still no luck in
getting some usable outputs tho, I might use my second INA122PA to try
making a simpler circuit which doesn't do the inversion and invert it
through software since I'm only going to use it on pc, but I don't know if
that would solve the problem.
As always thank you very much for your time!

Il giorno mar 12 lug 2022 alle ore 14:48 Scott Deakin <
***@***.***> ha scritto:

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

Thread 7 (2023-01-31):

Do the pedals fit in the original plastic housing without modification after this mod?

r-bman, 2023-01-31:
It looks like the loadcell holder protrudes too much for the pedals to fit back into the original plastic housing. Is that right?

Locoblade, 2023-01-31:
Fits fine with my G25 pedals as shown in my earlier post on here

rjm83, 2023-02-01:
It fit fine for me.  G29

On Tue, Jan 31, 2023, 3:36 PM Remi Boardman ***@***.***>
wrote:

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

GeekyDeaks, 2023-02-01:
Just to confirm what the others have mentioned, the top of the section that holds the loadcell is deliberately designed low enough to fit within the pedal housing

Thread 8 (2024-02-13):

Load cell positioning and mounting questions

Cptnyar77, 2024-02-13:
Hi there. So I have printed the "single" version. The load cell seems to fit on the bottom as pictured, but my question is:
What do you use to keep it in place and what is the small groove for that is slightly wider than the load cell?

GeekyDeaks, 2024-02-14:
> What do you use to keep it in place

The plunger should rest upon the upper part of the load cell and when the whole piston is re-assembled, the spring will provide a small amount of preload to keep everything from moving around.

> what is the small groove for that is slightly wider than the load cell?

I am not sure what you referring to, could you please elaborate?  The widest groove in the middle of the opening is the one that allows the load cell to be inserted into the assembly so that it can drop down into it's resting place at the bottom.  There gaps in the model above to allow the load cell to be inserted and below to allow the load cell to deform.  Does this help?

Cptnyar77, 2024-02-18:
Thank you. My load cell was smaller than the one designed for.

Next question the schematic shows 4 leads from the load cell but there are only 3 leads. Advice?

GeekyDeaks, 2024-02-19:
Ah, yeah that is not super clear.  It's pins 2 ,3 and 4 on the circuit diagram (Vin-, Vin+ and V+ with respect to the amplifier pins):

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

The load cell is used as the upper part of the wheatstone bridge. The resistors on the PCB are used to construct the lower section of the bridge.

Cptnyar77, 2024-02-24:
OK couple things.
1.) My g27 reads 5v (4.9) at the pin? Is this normal?

2.) I opted to go with a 4558 for the op amp (I have a bunch laying around from building guitar pedals.
Is this a bad choice?

3.) I can't seem to get this working with a single/balancing the wheatstone BUT it works just fine if I use two load cells.
My issue here is that my load cells are shaped slightly different. Would you be willing to share the model (single_holder.stl) in an editable format so I could try my hand at making these fit?

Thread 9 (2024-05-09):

Gerber file

Forza400, 2024-05-09:
Hello,

Im in the proces of building this awesome mod for my G29 pedals. I was wondering if you had the gerber file so i can have PCB way make this custom PCB. This way i don't have to make it myself trough the proces of etching.

GeekyDeaks, 2024-05-09:
I have some spare if you want me to post you a couple

Forza400, 2024-05-09:
Man that would be more then i could hope for. If you can estimate the cost of sending it to Belgium i can pay you with paypal for your pcb and postage fees?

GeekyDeaks, 2024-05-09:
Ah, if you are keen enough to tackle this then posting a few PCBs is the least I can do to help :D. Just send me your address to sdeaks@gmail.com and I'll sort it out early next week.  I suspect they will fit in a standard letter anyway.

Forza400, 2024-05-15:
Hi, all the parts have arived and i'm 3d printing the rest. While printing i was looking at the diagram and reading trough all the comments. I saw you mention putting a cap on C1. What do you mean with a cap? If i understand everything correctly when i want to build a single loadcel no clutch type of pcb i need to:
-Leave R_REF empty, but bridge the middle and the right hand pin.
-Connect the largest of the 1k resistors to R1 and the other one to R2.
-Connect the 10ohm trimpot to R_BAL1
-Connect the 1K ohm trimpot to R_GAIN
-Put some ?magical 'cap'? on C1
Sorry for these novice questions but i wanna make sure i don't mess up and get frustrated :)

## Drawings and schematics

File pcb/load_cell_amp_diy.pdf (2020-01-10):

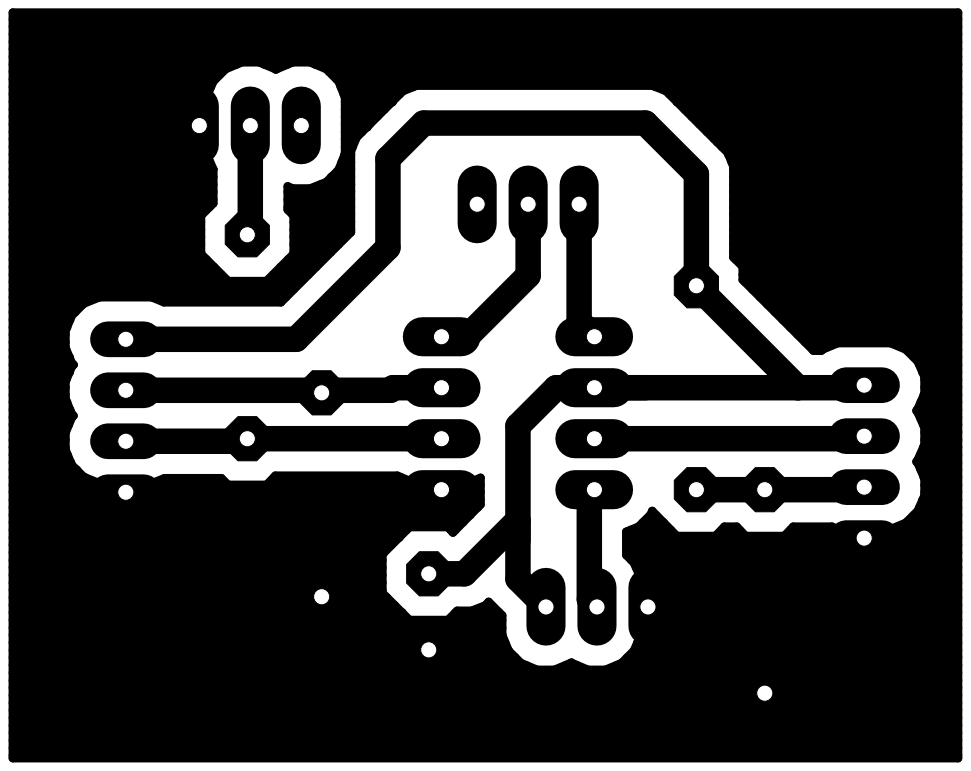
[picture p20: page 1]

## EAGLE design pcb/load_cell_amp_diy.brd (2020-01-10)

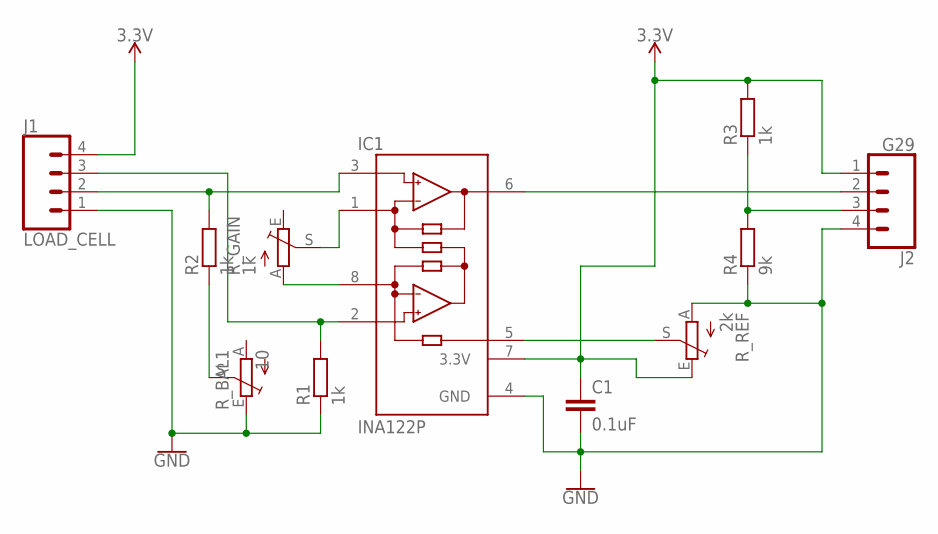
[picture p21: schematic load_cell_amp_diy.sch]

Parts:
C1: 0.1uF; C2.5-3
IC1: INA122P; DIL08
J1: LOAD_CELL; 04P
J2: G29; 04P
R1, R2, R3: 1k; 0207/10
R4: 9k; 0207/10
R_BAL1: 10; RJ9W
R_GAIN: 1k; RJ9W
R_REF: 2k; RJ9W

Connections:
3.3V: C1.1, IC1.7 (3.3V), J1.4, J2.1, R3.2, R_REF.E
CLUTCH: IC1.6 (OUT), J2.2
GND: C1.2, IC1.4 (GND), J1.1, J2.4, R1.1, R4.1, R_BAL1.E, R_REF.A
unnamed: IC1.8 (RG), R_GAIN.A
unnamed: IC1.1 (RG), R_GAIN.S
unnamed: IC1.3 (+IN), J1.2, R2.2
unnamed: IC1.2 (-IN), J1.3, R1.2
unnamed: R2.1, R_BAL1.S
unnamed: IC1.5 (REF), R_REF.S
unnamed: J2.3, R3.1, R4.2

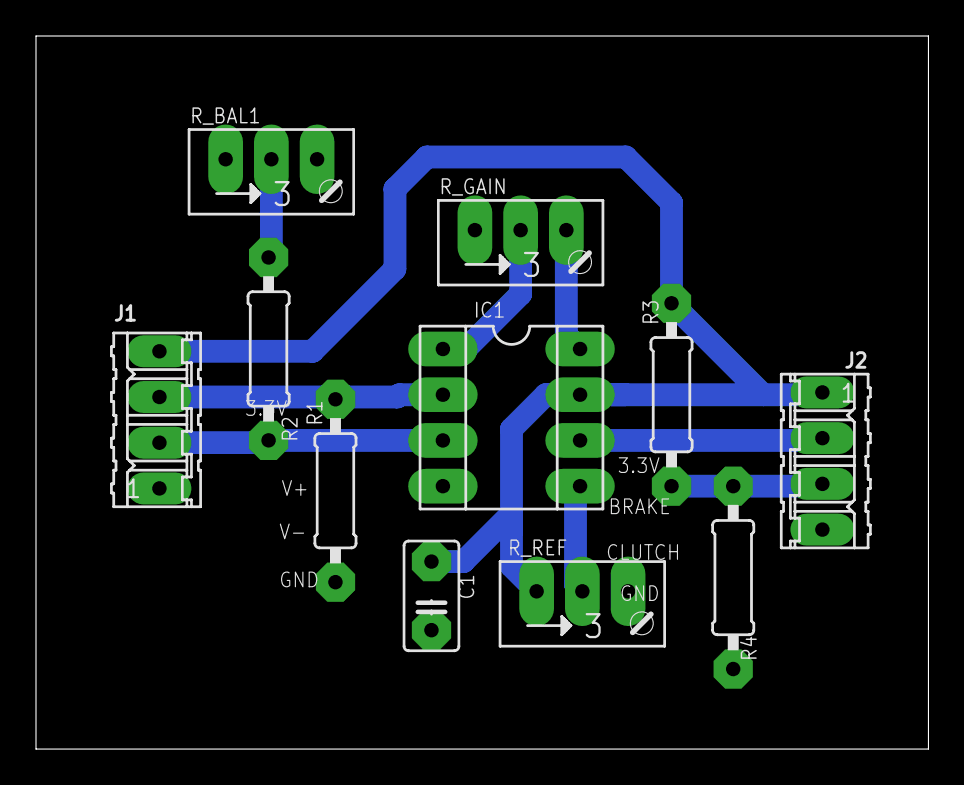
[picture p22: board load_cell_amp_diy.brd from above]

Board: 2 copper layers, 49.6 x 39.6 mm, 11 parts (0 on the bottom side), 10 nets.

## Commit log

2019-12-24 fixed ERC errors
    [g29_load_cell.brd, g29_load_cell.sch]
2019-12-24 renamed PCB and schematic
    [load_cell_amp.brd, load_cell_amp.sch]
2019-12-26 added stl files for cell holder
    [holder.stl, spacer.stl]
2019-12-26 fixed links to stl files
2019-12-26 second attempt to fix stl links
2019-12-27 updated holder model
    [holder.stl]
2019-12-27 added cell retainer to holder model
    [holder.stl, spacer.stl]
2019-12-27 hide retainer
    [holder.stl]
2019-12-27 added schematic image
2019-12-28 renamed IC2 to IC1
    [load_cell_amp.brd, load_cell_amp.sch]
2019-12-28 updated schematic image
2019-12-30 tweaked holder model
    [holder.stl]
2020-01-04 updated schematic to support single cell
    [load_cell_amp.brd, load_cell_amp.sch]
2020-01-04 added single cell model
    [dual_holder.stl, dual_spacer.stl, single_holder.stl]
2020-01-04 fixed dual spacer model link
2020-01-05 updated single cell model
    [single_holder.stl]
2020-01-08 DIY PCB board for etching
    [load_cell_amp_diy.brd, load_cell_amp_diy.sch]
2020-01-10 updated diy board to help etching and soldering
    [load_cell_amp_diy.brd]
2020-02-23 increased spring guide diameter
    [single_holder.stl]
2020-02-23 diy pcb image
2020-02-23 diy pcb updates
2020-10-22 added plunger scad
    [plunger.scad]
2020-10-22 add plunger
    [bottom.scad, plunger.scad, plunger_bottom.stl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]

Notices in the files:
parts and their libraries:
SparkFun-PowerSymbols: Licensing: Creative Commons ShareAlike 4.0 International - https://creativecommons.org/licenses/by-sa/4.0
